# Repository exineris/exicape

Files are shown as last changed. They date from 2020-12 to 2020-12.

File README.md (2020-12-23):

# Exi Cape

## 1.はじめに

[BeagleBoard](https://beagleboard.org/)に、産業機器を接続するためのインターフェースボード([CAPE](https://beagleboard.org/capes))です。

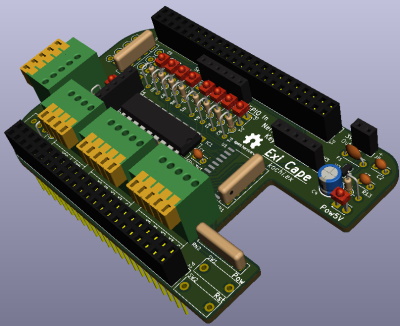
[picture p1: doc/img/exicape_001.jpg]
pcb01 外観

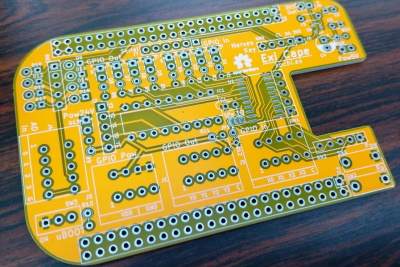
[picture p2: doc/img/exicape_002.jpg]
pcb02 基板


**Note**

Please import this library before using this repository.
<https://github.com/trihome/KiCad_MyLibrary>

## 2.仕様

[回路図](./doc/ExiCape.pdf)

|機能|仕様|補足|
|:--|:--|:--|
|出力|4ch|非絶縁。シンク（NPN）・ソース（PNP）駆動切り替え可能。各chの動作確認LEDあり。|
|入力|4ch|〃|
|AD変換|10bit 2ch|非絶縁・入力保護のダイオード付き|
|暗号化|ATECC508A/608A|[NervesKey](https://github.com/nerves-hub/nerves_key)の接続に対応|
|外部操作スイッチ|Power, Reset, μBoot||
|外部UART端子|あり x 1|Beagle Bone GreenのUARTに直結|
|電源|5V系/24V系は個別に供給|ポリスイッチ（過電流防止）あり|

## 3.License

This is under [CC-BY-SA](https://creativecommons.org/licenses/by-sa/4.0/).

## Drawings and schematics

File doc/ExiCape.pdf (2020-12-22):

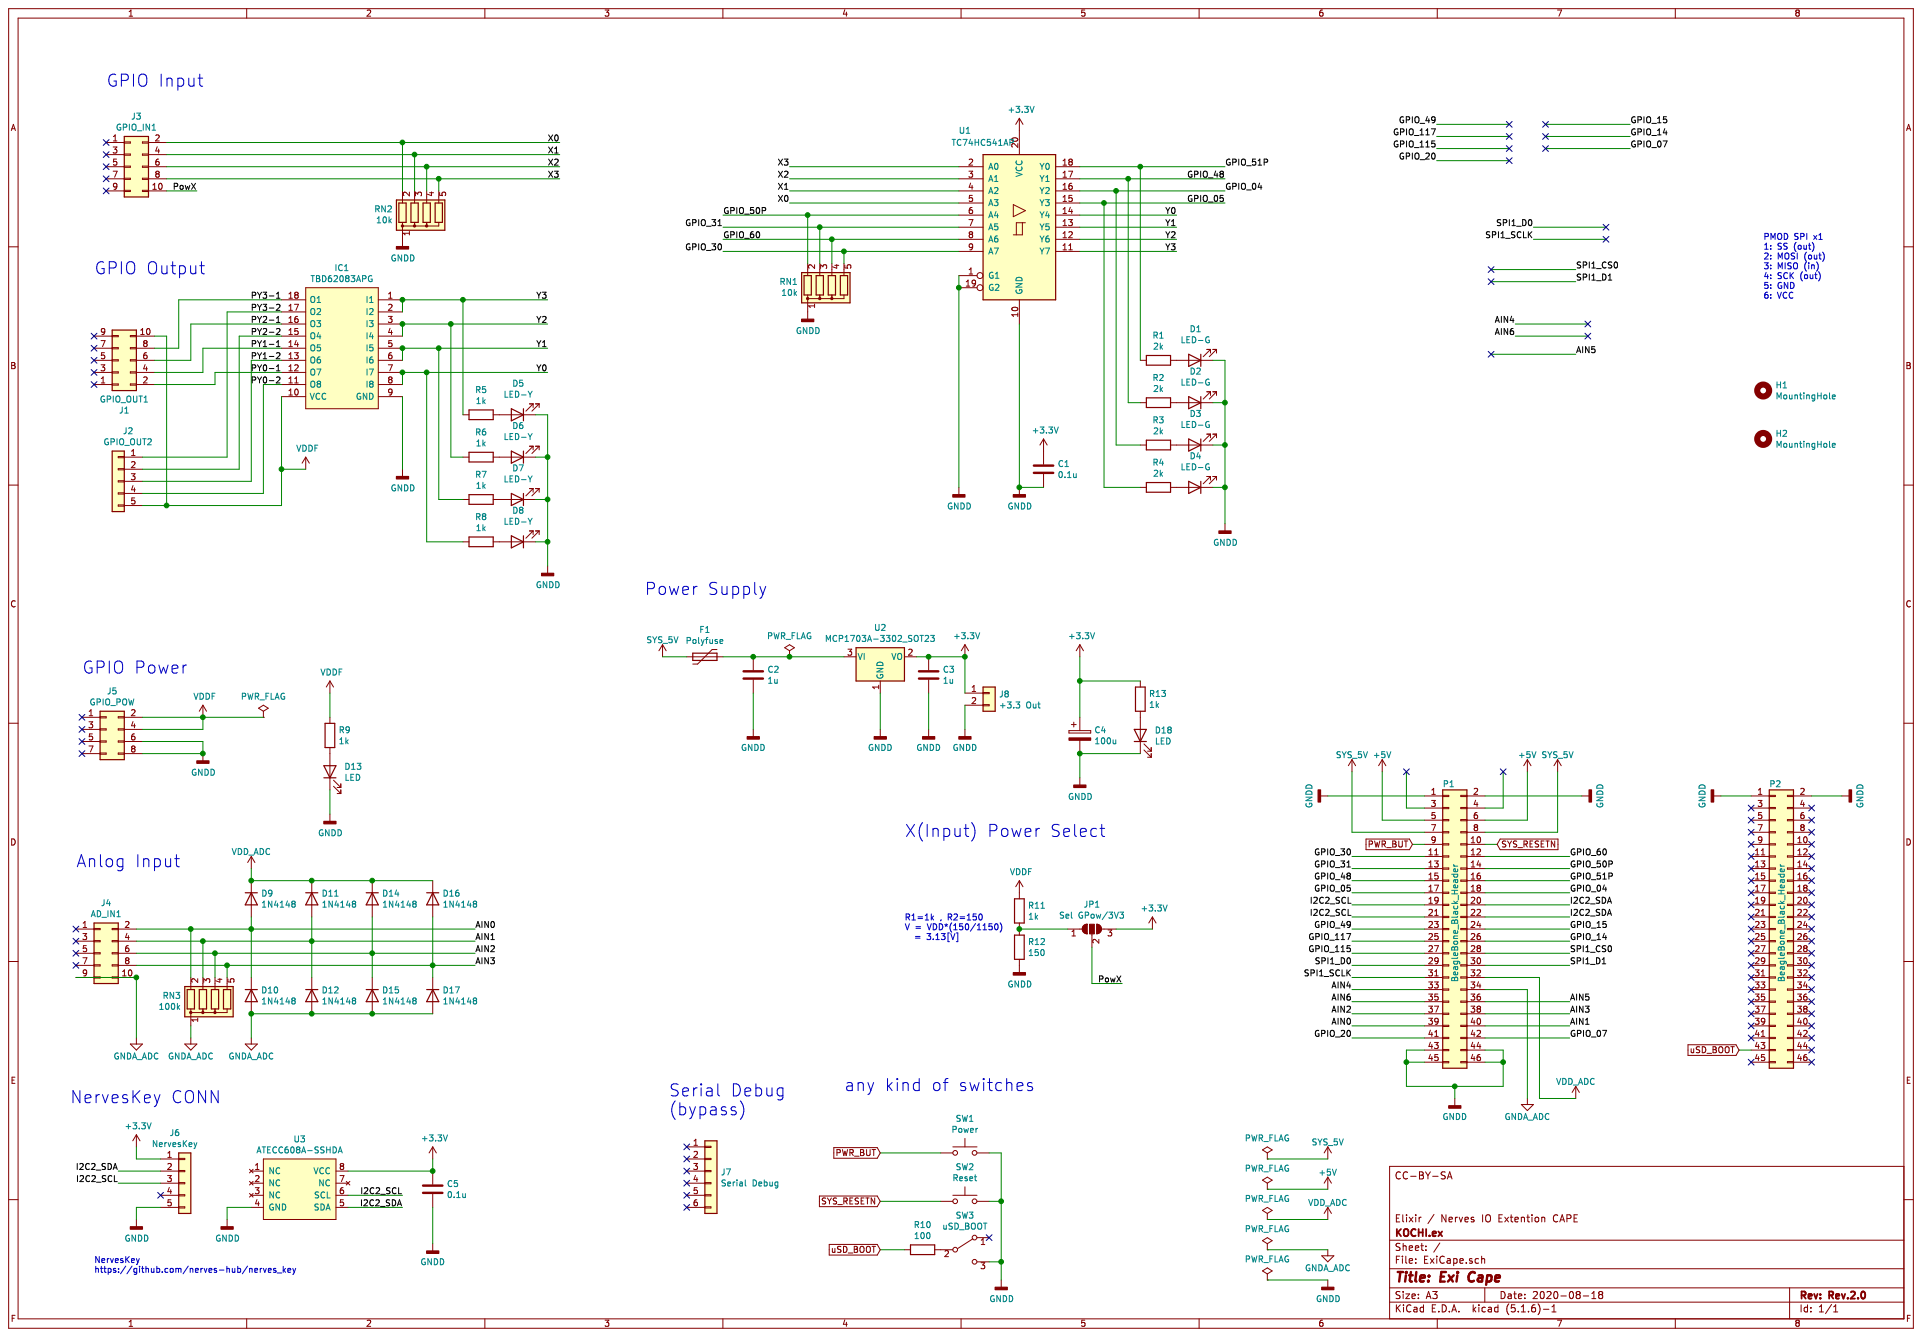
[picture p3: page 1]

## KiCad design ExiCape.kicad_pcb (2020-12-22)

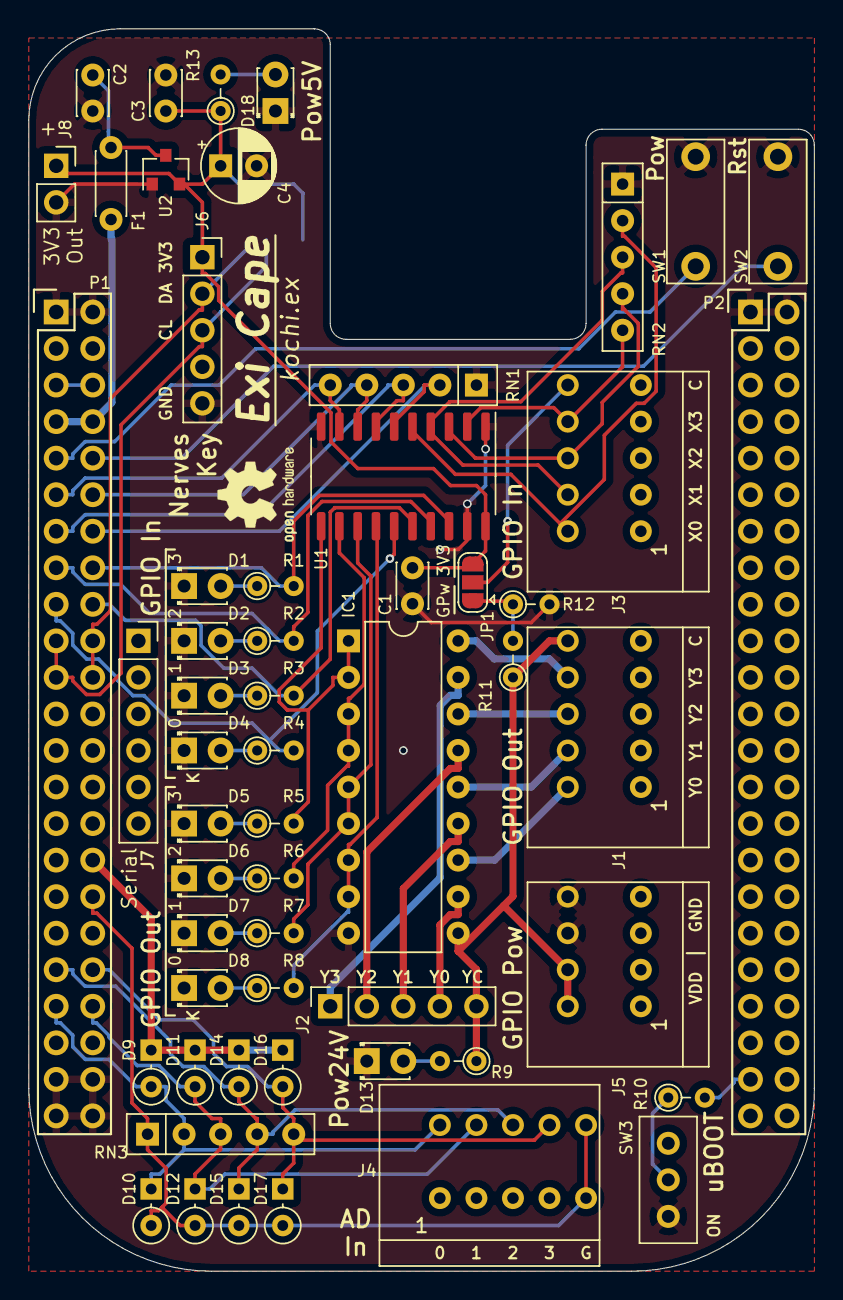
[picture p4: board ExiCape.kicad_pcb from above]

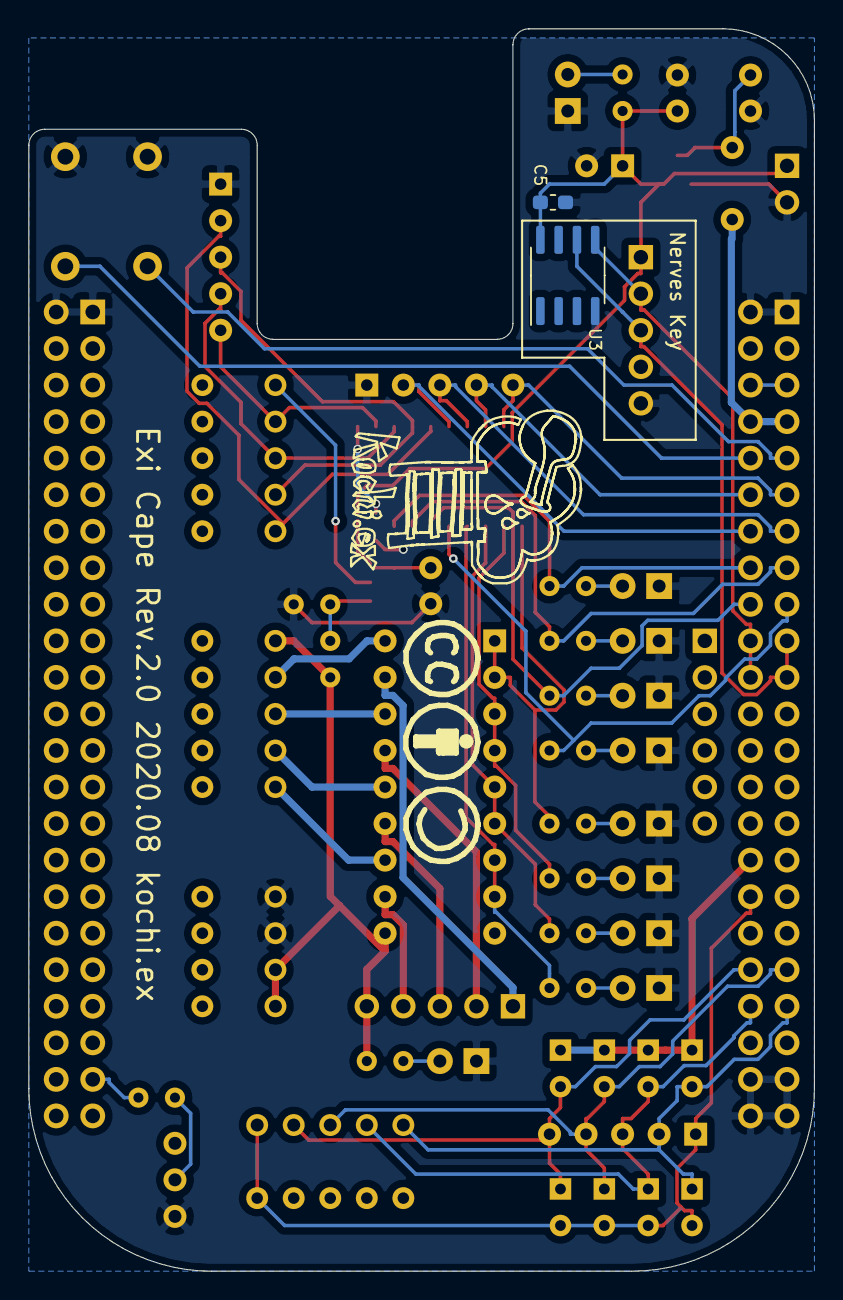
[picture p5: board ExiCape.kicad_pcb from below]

Board: 2 copper layers, 54.6 x 86.4 mm, 60 parts (2 on the bottom side), 54 nets.

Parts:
C1: 0.1u; C_Disc_D3.0mm_W2.0mm_P2.50mm
C2, C3: 1u; C_Disc_D3.0mm_W2.0mm_P2.50mm
C4: 100u; CP_Radial_D5.0mm_P2.50mm
C5: 0.1u; C_0603_1608Metric_Pad1.05x0.95mm_HandSolder
D1, D2, D3, D4: LED-G; LED_D1.8mm_W3.3mm_H2.4mm
D5, D6, D7, D8: LED-Y; LED_D1.8mm_W3.3mm_H2.4mm
D9, D10, D11, D12, D14, D15, D16, D17: 1N4148; D_DO-34_SOD68_P2.54mm_Vertical_KathodeUp
D13, D18: LED; LED_D1.8mm_W3.3mm_H2.4mm
F1: Polyfuse; C_Disc_D4.3mm_W1.9mm_P5.00mm
H1: MountingHole; OSHW-Logo2_7.3x6mm_SilkScreen
H2: MountingHole; CC-BY-SA
IC1: TBD62083APG; DIP-18_W7.62mm
J1: GPIO_OUT1; Terminal_TB401-1-5-E
J2: GPIO_OUT2; PinSocket_1x05_P2.54mm_Vertical
J3: GPIO_IN1; Terminal_TB401-1-5-E
J4: AD_IN1; Terminal_TB401-1-5-E
J5: GPIO_POW; Terminal_TB401-1-4-E
J6: NervesKey; PinSocket_1x05_P2.54mm_Vertical
J7: Serial Debug; PinSocket_1x06_P2.54mm_Vertical
J8: +3.3 Out; PinSocket_1x02_P2.54mm_Vertical
JP1: Sel GPow/3V3; SolderJumper-3_P1.3mm_Open_RoundedPad1.0x1.5mm
P1, P2: BeagleBone_Black_Header; Socket_BeagleBone_Black
R1, R2, R3, R4: 2k; R_Axial_DIN0204_L3.6mm_D1.6mm_P2.54mm_Vertical
R5, R6, R7, R8, R9, R11, R13: 1k; R_Axial_DIN0204_L3.6mm_D1.6mm_P2.54mm_Vertical
R10: 100; R_Axial_DIN0204_L3.6mm_D1.6mm_P2.54mm_Vertical
R12: 150; R_Axial_DIN0204_L3.6mm_D1.6mm_P2.54mm_Vertical
RN1, RN2: 10k; R_Array_SIP5
RN3: 100k; R_Array_SIP5
SW1: Power; TactileSwitch_TVBP06-B043C
SW2: Reset; TactileSwitch_TVBP06-B043C
SW3: uSD_BOOT; Switch_SS12D01G4
U1: TC74HC541AP; SO-20_5.3x12.6mm_P1.27mm
U2: MCP1703A-3302_SOT23; SOT-23
U3: ATECC608A-SSHDA; SOIC-8_3.9x4.9mm_P1.27mm

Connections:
+3V3: C1.1, C3.1, C4.1, C5.1, J6.1, J8.1, JP1.3, R13.1, U1.20, U2.2, U3.8
+5V: P1.5, P1.6
/AIN0: D9.2, D10.1, J4.2, P1.39, RN3.2
/AIN1: D11.2, D12.1, J4.4, P1.40, RN3.3
/AIN2: D14.2, D15.1, J4.6, P1.37, RN3.4
/AIN3: D16.2, D17.1, J4.8, P1.38, RN3.5
/GPIO_04: P1.18, R3.2, U1.16
/GPIO_05: P1.17, R4.2, U1.15
/GPIO_30: P1.11, RN1.5, U1.9
/GPIO_31: P1.13, RN1.3, U1.7
/GPIO_48: P1.15, R2.2, U1.17
/GPIO_50P: P1.14, RN1.2, U1.6
/GPIO_51P: P1.16, R1.2, U1.18
/GPIO_60: P1.12, RN1.4, U1.8
/I2C2_SCL: J6.3, P1.19, P1.21, U3.6
/I2C2_SDA: J6.2, P1.20, P1.22, U3.5
/PY0-1: IC1.12, J1.2
/PY0-2: IC1.11, J2.4
/PY1-1: IC1.14, J1.4
/PY1-2: IC1.13, J2.3
/PY2-1: IC1.16, J1.6
/PY2-2: IC1.15, J2.2
/PY3-1: IC1.18, J1.8
/PY3-2: IC1.17, J2.1
/PowX: J3.10, JP1.2
/X0: J3.2, RN2.2, U1.5
/X1: J3.4, RN2.3, U1.4
/X2: J3.6, RN2.4, U1.3
/X3: J3.8, RN2.5, U1.2
/Y0: IC1.7, IC1.8, R8.2, U1.14
/Y1: IC1.5, IC1.6, R7.2, U1.13
/Y2: IC1.3, IC1.4, R6.2, U1.12
/Y3: IC1.1, IC1.2, R5.2, U1.11
GNDA_ADC: D10.2, D12.2, D15.2, D17.2, J4.9, J4.10, P1.34, RN3.1
GNDD: C1.2, C2.2, C3.2, C4.2, C5.2, D1.1, D2.1, D3.1, D4.1, D5.1, D6.1, D7.1, D8.1, D13.1, D18.1, IC1.9, J5.6, J5.8, J6.5, J8.2, P1.1, P1.2, P1.43, P1.44, P1.45, P1.46, P2.1, P2.2, R12.2, RN1.1, RN2.1, SW1.2, SW2.2, SW3.3, U1.1, U1.10, U1.19, U2.1, U3.4
unnamed: C2.1, F1.1, U2.3
unnamed: D1.2, R1.1
unnamed: D2.2, R2.1
unnamed: D3.2, R3.1
unnamed: D4.2, R4.1
unnamed: D5.2, R5.1
unnamed: D6.2, R6.1
unnamed: D7.2, R7.1
unnamed: D8.2, R8.1
unnamed: D13.2, R9.2
unnamed: D18.2, R13.2
unnamed: JP1.1, R11.2, R12.1
unnamed: R10.1, SW3.2
PWR_BUT: P1.9, SW1.1
SYS_5V: F1.2, P1.7, P1.8
SYS_RESETN: P1.10, SW2.1
VDDF: IC1.10, J1.10, J2.5, J5.2, J5.4, R9.1, R11.1
VDD_ADC: D9.1, D11.1, D14.1, D16.1, P1.32
uSD_BOOT: P2.43, R10.2

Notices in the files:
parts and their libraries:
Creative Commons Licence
